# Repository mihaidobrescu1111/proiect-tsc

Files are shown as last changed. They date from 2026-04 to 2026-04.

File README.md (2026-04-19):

# InkTime - Hardware Design Repository

Proiect hardware pentru un smartwatch open-source, low-cost, realizat în Fusion 360 Electronics (EAGLE format `.sch` + `.brd`).

## Structura repository-ului

- Hardware
	- [Schematic.sch](Hardware/Schematic.sch)
	- [PCB.brd](Hardware/PCB.brd)
- Manufacturing
	- (de adăugat la EVT: `gerbers.zip`, `.bom`, `.cpl`)
- Mechanical
	- (de adăugat la EVT: model complet `.step` și fișier Fusion360)
- Images
	- (de adăugat: randări PCB și ansamblu)

## Diagramă bloc

```mermaid
flowchart LR
  BATT["LiPo Battery"] --> PMIC["BQ25180 Charger + Power Path"]
  USB["USB-C J4"] --> ESD["USBLC6 ESD"]
  USB --> PMIC
  PMIC --> SYS["System Rail"]

  SYS --> MCU["nRF52840 U1"]
  SYS --> FG["MAX17048 Fuel Gauge U3"]
  SYS --> HAPTIC["DRV2605 Vibrator Driver IC1"]
  SYS --> EPDPWR["RT6160 plus passives IC9"]

  MCU --> RFM["Matching L/C"]
  RFM --> ANT["2450AT18B100E Antenna"]

  MCU --> SWD["TC2030 SWD Header + Test Pads"]
  MCU --> DISP["EPD Connector J1"]
  MCU --> BTN["3 Buttons"]
```

## BOM (Bill of Materials)

| Ref / Grup | Componentă | Qty | Funcție | JLC / Source link | Datasheet |
|---|---|---:|---|---|---|
| `U1` | nRF52840-QFAA | 1 | MCU BLE + USB | https://jlcpcb.com/parts?searchTxt=nRF52840 | https://infocenter.nordicsemi.com/pdf/nRF52840_PS_v1.1.pdf |
| `IC1` | DRV2605 | 1 | Driver haptic | https://jlcpcb.com/parts?searchTxt=DRV2605 | https://www.ti.com/lit/ds/symlink/drv2605.pdf |
| `IC9` | RT6160A | 1 | Convertor DC/DC pentru rail-uri EPD | https://jlcpcb.com/parts?searchTxt=RT6160 | https://www.richtek.com/assets/product_file/RT6160A/DS6160A-05.pdf |
| `U3` | MAX17048G+T10 | 1 | Fuel gauge Li-Ion | https://jlcpcb.com/parts?searchTxt=MAX17048 | https://www.analog.com/media/en/technical-documentation/data-sheets/MAX17048-MAX17049.pdf |
| `ANT1` | 2450AT18B100E | 1 | Antenă 2.4 GHz | https://jlcpcb.com/parts?searchTxt=2450AT18B100E | https://www.johansontechnology.com/datasheets/2450AT18B100E.pdf |
| `J4` | USB-C 16P (KH-TYPE-C-16P) | 1 | Alimentare + USB | https://jlcpcb.com/parts?searchTxt=TYPE-C-16P | https://datasheet.lcsc.com/lcsc/2006231106_Kinghelm-KH-TYPE-C-16P_C709357.pdf |
| `D1` | USBLC6-2SC6Y | 1 | Protecție ESD USB | https://jlcpcb.com/parts?searchTxt=USBLC6-2SC6Y | https://www.st.com/resource/en/datasheet/usblc6-2.pdf |
| `D3`,`D4`,`D5` | MBR0530 | 3 | Schottky diode | https://jlcpcb.com/parts?searchTxt=MBR0530 | https://www.onsemi.com/pdf/datasheet/mbr0530t1-d.pdf |
| `Q3` | SI1308EDL | 1 | MOSFET control alimentare | https://jlcpcb.com/parts?searchTxt=SI1308EDL | https://www.vishay.com/docs/63399/si1308edl.pdf |
| `DMG2305UX-7` | PMOS | 1 | Comutare rail | https://jlcpcb.com/parts?searchTxt=DMG2305UX | https://www.diodes.com/assets/Datasheets/DMG2305UX.pdf |
| `J1` | 503480-2400 | 1 | Conector display / FPC | https://jlcpcb.com/parts?searchTxt=503480-2400 | https://www.molex.com/pdm_docs/sd/5034802400_sd.pdf |
| `J2` | TC2030-IDC | 1 | Debug/programare SWD | https://www.tag-connect.com/product/tc2030-idc-nl | https://www.tag-connect.com/wp-content/uploads/bsk-pdf-manager/TC2030-IDC-NL.pdf |
| `SW_UP`,`SW_ENT`,`SW_DN` | EVPAKE31A | 3 | Butoane UI | https://jlcpcb.com/parts?searchTxt=EVP-AKE31A | https://industrial.panasonic.com/cdbs/www-data/pdf/ASQ0000/ASQ0000CE153.pdf |
| `X1` | 32 MHz crystal | 1 | Clock HF MCU | https://jlcpcb.com/parts?searchTxt=32MHz%202016 | https://www.nxp.com/docs/en/data-sheet/NX3225SA.pdf |
| `X2` | 32.768 kHz crystal | 1 | RTC clock | https://jlcpcb.com/parts?searchTxt=32.768kHz%203215 | https://www.abracon.com/datasheets/ABS06.pdf |
| `R*` | Rezistențe 0201 | 15 | Bias, pull-up/pull-down, sense | https://jlcpcb.com/parts?searchTxt=0201%20resistor | - |
| `C*`,`EPD_C*` | Condensatoare 0201/0402/0603 | 39 | Decuplare, filtrare, RF matching, EPD charge pump | https://jlcpcb.com/parts?searchTxt=0201%20capacitor | - |
| `L1`,`L2`,`L3`,`L5`,`L7` | Inductoare (RF + power) | 5 | Matching RF + convertoare | https://jlcpcb.com/parts?searchTxt=0402%20inductor | - |
| `TP_*` | Test pads TP20R | 14 | DFT: SWD, alimentări, I2C, reset | https://jlcpcb.com/parts?searchTxt=test%20point | - |

## Funcționalitate hardware detaliată

### Domeniu alimentare

- Intrare alimentare prin USB-C (`J4`) + baterie LiPo.
- Lanț PMIC/charger (`BQ25180`) definit în schemă.
- Fuel gauge (`MAX17048`, `U3`) pentru estimarea stării bateriei.
- Convertor boost/buck (`RT6160`, `IC9`) pentru rail-uri auxiliare folosite de subsistemul display/EPD.
- Diode Schottky (`D3..D5`) și MOSFET-uri (`Q3`, `DMG2305UX-7`) pentru protecție/comutare rail.

### Sub-sistem MCU + RF

- MCU principal: `nRF52840` (`U1`).
- Clock-uri externe:
	- `X1` 32 MHz pentru radio/HF.
	- `X2` 32.768 kHz pentru RTC/low-power.
- Lanț RF de matching cu `L1`, `L3`, `C3`, `C4` către `ANT1`.

### Interfețe externe și debug

- USB-C + protecție ESD (`D1`).
- Header SWD Tag-Connect (`J2`) + test pads (`TP_SWDIO`, `TP_SWDCLK`, `TP_SWO`, `TP_RESET`).
- Test pads de alimentare și I2C (`TP_3V3`, `TP_VBAT`, `TP_GND`, `TP_SDA`, `TP_SCL`, etc.).

### Sub-sistem UI / haptic / display

- 3 butoane (`SW_UP`, `SW_ENT`, `SW_DN`).
- Driver haptic `DRV2605` (`IC1`).
- Conector display (`J1`) + pasive dedicate EPD (`EPD_C*`, `R_PWR_EPD`, etc.).

## Mapare pini nRF52840

| Pin nRF52840 | Net | Rol |
|---|---|---|
| `D+` | `N$58` | USB data plus (neconfirmat funcțional în documentația text-only) |
| `D-` | `N$59` | USB data minus (neconfirmat funcțional în documentația text-only) |
| `SWDCLK` | `SWDCLK` | Debug clock expus la TP_SWDCLK și header SWD |
| `SWDIO` | `SWDIO` | Debug data bidirecțional expus la TP_SWDIO și header SWD |
| `SWO` | `SWO` | Serial Wire Output (trace/debug) expus la TP_SWO |
| `NRST` | `NRST` | Reset hardware expus la TP_RESET |
| `I2C_SCL` | `I2C_SCL` | Magistrală I2C clock expusă la TP_SCL |
| `I2C_SDA` | `I2C_SDA` | Magistrală I2C data expusă la TP_SDA |
| `VDD` monitor/test | `VDD_3V3`, `VDD_3V3_MON` | Rail principal 3V3 + testpoint monitor dedicat |
| `VREG` | `VREG` | Rail regulator intern/auxiliar expus la TP_VREG |
| `VBAT` | `VBAT` | Rail baterie expus la TP_VBAT |
| `ANT` | `RF_MCU_MATCH` -> `RF_MATCH_ANT` | Lanț RF: pin ANT MCU -> matching -> antenă |
| `EPD control` | `EPD_OP`, `EPD_ON` | Semnale EPD expuse în DFT prin TP_OP/TP_ON |
| `XC1`, `XC2` | `N$78`, `N$79` | Cristal 32 MHz (neconfirmat pentru redenumire în etapa text-only) |
| `P0.00/XL1`, `P0.01/XL2` | `N$112`, `N$114` | Cristal 32.768 kHz (neconfirmat pentru redenumire în etapa text-only) |
| `VBUS`, `VDDH`, `DECx`, `VSS` | diverse `N$xx` și `GND` | Alimentare/decuplare conform recomandări Nordic (parțial neconfirmat) |

### GPIO generale

`P0.02 ... P0.31`, `P1.00 ... P1.15` sunt prezente pe neturi interne `N$44...N$111`.

## Consumul de putere (power budget estimativ, fără măsurători)

Estimările de mai jos sunt orientative și bazate pe:

- valori tipice din datasheet-uri (`nRF52840`, `MAX17048`, `DRV2605`, `RT6160A`, plus curenți pasivi/leakage)
- arhitectura din schemă (rail-uri separate pentru MCU, EPD power path și haptic)
- ipoteză de alimentare LiPo în domeniul nominal, fără derating termic sever

Nu reprezintă rezultate de test în laborator.

### Scenarii de consum

| Scenariu | Interval estimat | Bază estimare |
|---|---:|---|
| Sleep | `15 ... 60 µA` | nRF52840 în low-power + fuel gauge activ + leakage rail-uri |
| Activ BLE periodic | `1.5 ... 6 mA` mediu | duty-cycle radio BLE + CPU wakeups periodice + periferice de bază |
| Refresh display | `8 ... 25 mA` pe durata refresh | convertor EPD (`RT6160A`) + comutări pe rail-urile EPD + control MCU |
| Haptic activ | `20 ... 85 mA` în impuls | `DRV2605` + motor/vibrator (depinde puternic de pattern/amplitudine) |

Energia pentru o baterie de capacitate $C_{bat}$ [mAh] la curent mediu $I_{avg}$ [mA]:

$$
t_{autonomie}[h] \approx \frac{C_{bat}}{I_{avg}}
$$

Exemple numerice (cu ipoteze explicite):

- Caz A, baterie `180 mAh`, profil mixt cu $I_{avg} = 2.5$ mA (BLE periodic + refresh EPD ocazional):

$$
t \approx \frac{180}{2.5} = 72\ h \approx 3.0\ zile
$$

- Caz B, baterie `300 mAh`, profil predominant sleep cu burst-uri, $I_{avg} = 0.8$ mA:

$$
t \approx \frac{300}{0.8} = 375\ h \approx 15.6\ zile
$$

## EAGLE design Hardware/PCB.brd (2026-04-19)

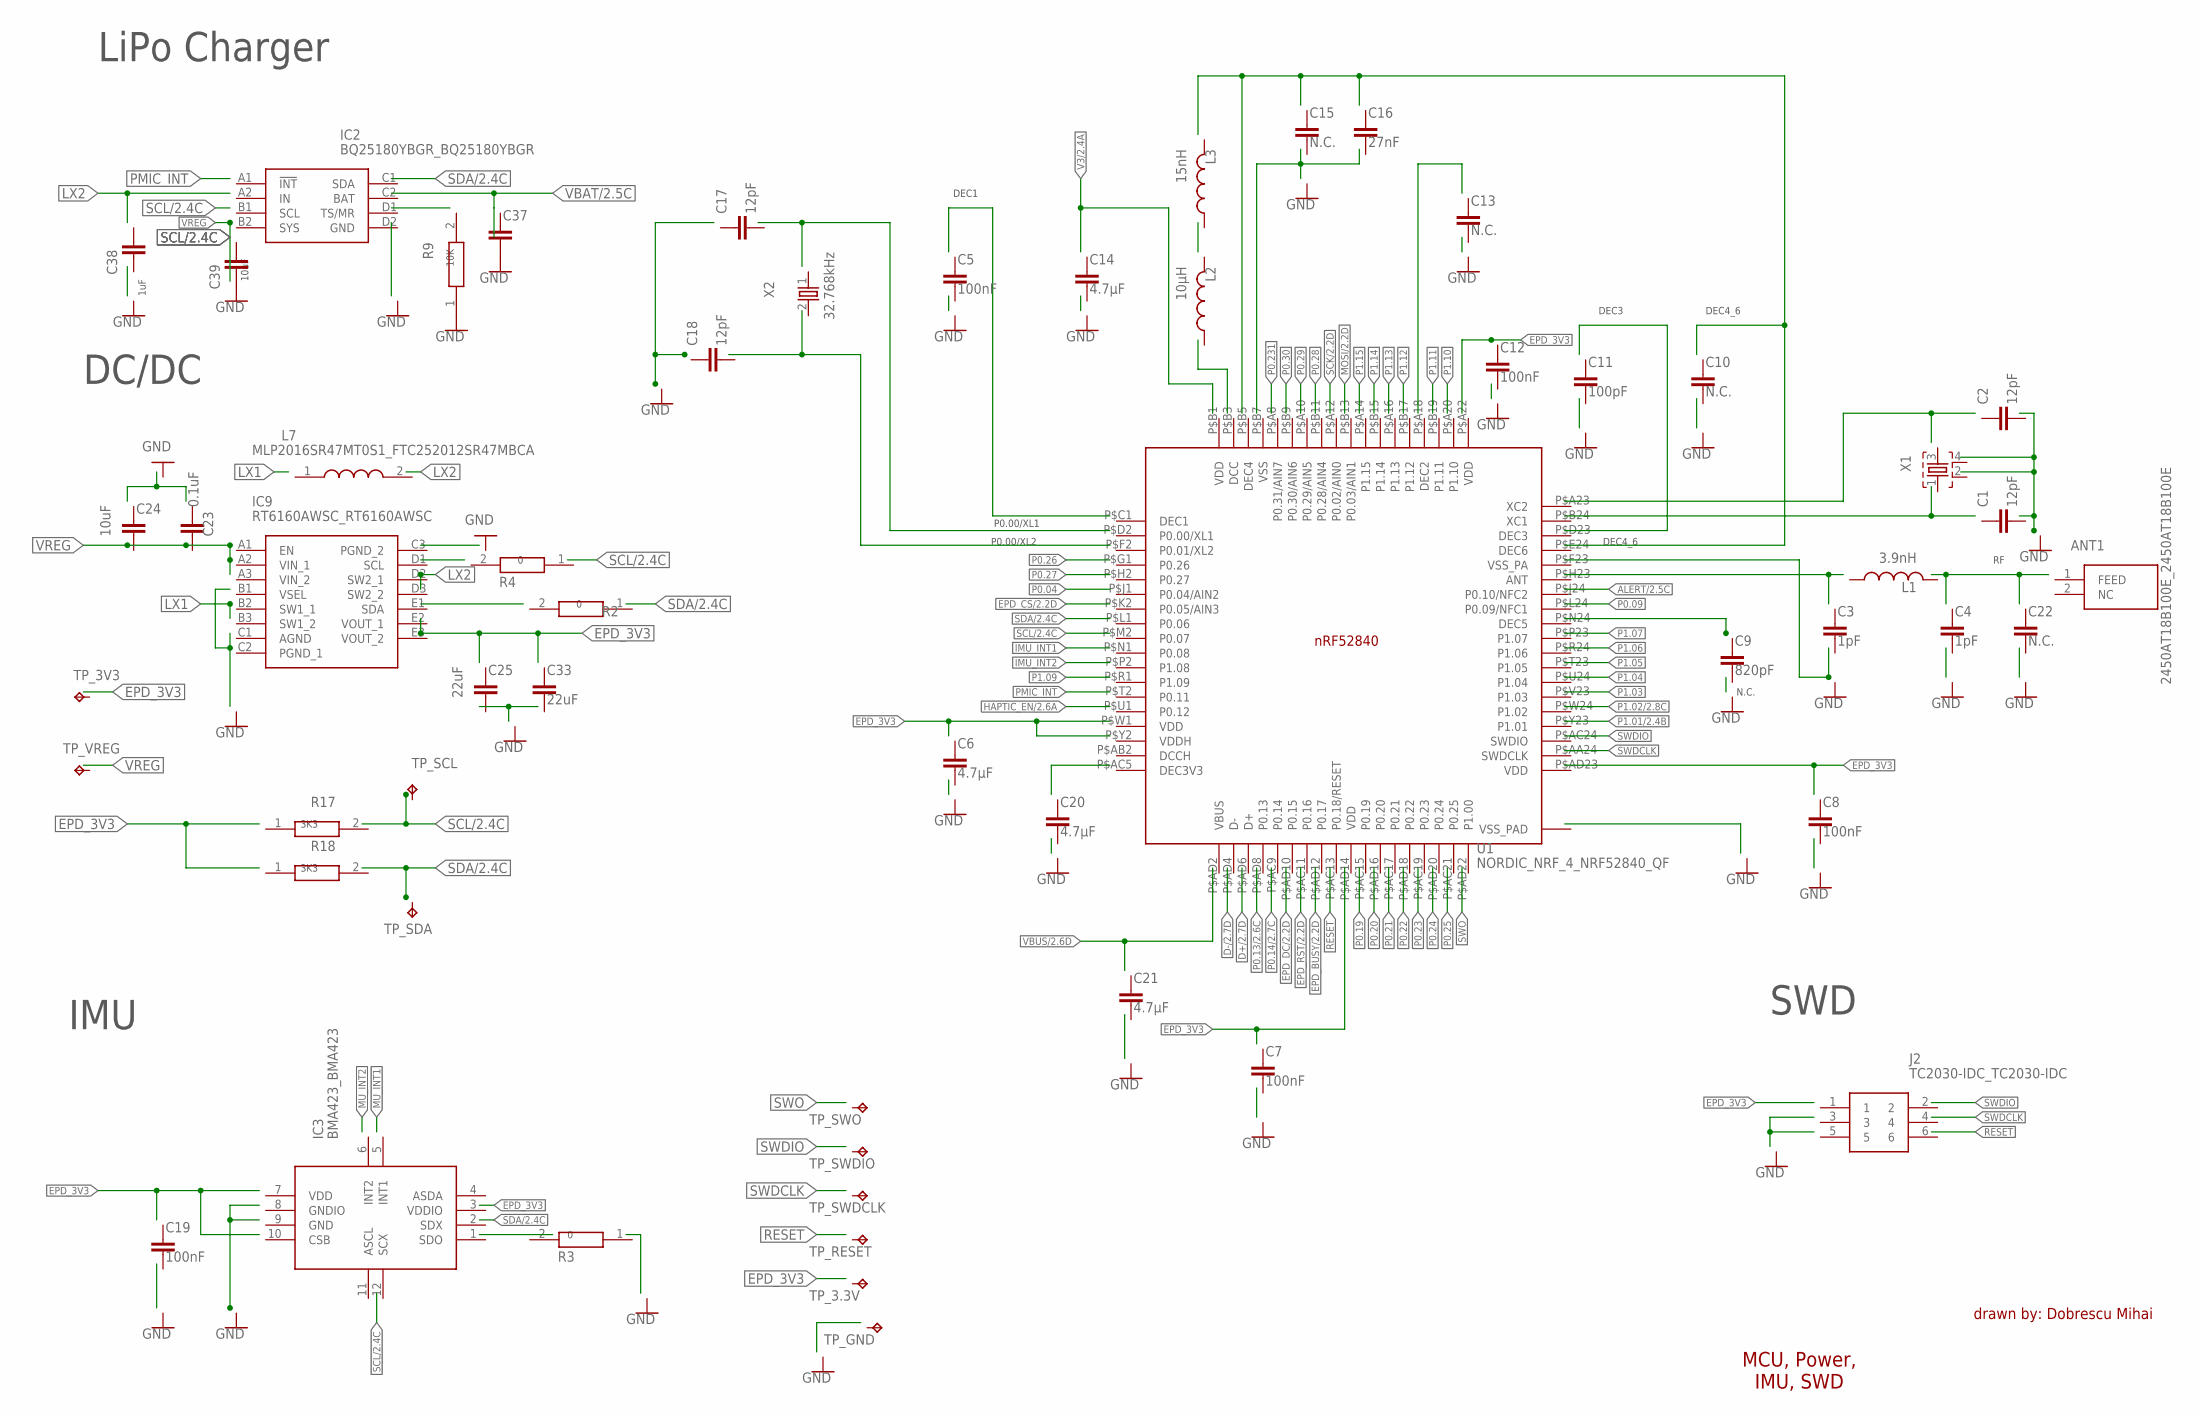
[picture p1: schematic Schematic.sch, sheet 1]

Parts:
ANT1: 2450AT18B100E_2450AT18B100E; 2450AT18B100E_ANTC3216X140N
C1, C2, C17, C18: 12pF; NORDIC_NRF_3_RESC0201_L
C3, C4: 1pF; NORDIC_NRF_3_RESC0201_L
C5, C7, C8, C12, C19: 100nF; NORDIC_NRF_3_RESC0201_L
C6, C14, C20, C21: 4.7µF; NORDIC_NRF_3_RESC0201_L
C9: 820pF; NORDIC_NRF_3_RESC0201_L
C10, C13, C15, C22: N.C.; NORDIC_NRF_3_RESC0201_L
C11: 100pF; NORDIC_NRF_3_RESC0201_L
C16: 27nF; NORDIC_NRF_3_RESC0201_L
C23: 0.1uF; NORDIC_NRF_3_RESC0201_L
C24: 10uF; NORDIC_NRF_3_RESC0201_L
C25, C33: 22uF; NORDIC_NRF_3_RESC0201_L
C37, C38, C39: NORDIC_NRF_3_CAPACITOR_0201_L; NORDIC_NRF_3_RESC0201_L
IC2: BQ25180YBGR_BQ25180YBGR; BQ25180YBGR_BGA8C40P2X4_100X155X50
IC3: BMA423_BMA423
IC9: RT6160AWSC_RT6160AWSC; RT6160AWSC_BGA15C40P3X5_140X230X60
J2: TC2030-IDC_TC2030-IDC; TC2030-IDC_TC2030IDC
L1: 3.9nH; NORDIC_NRF_2_RESC0402_L
L2: 10µH; NORDIC_NRF_2_RESC0402_L
L3: 15nH; NORDIC_NRF_2_RESC0402_L
L7: MLP2016SR47MT0S1_FTC252012SR47MBCA; MLP2016SR47MT0S1_INDC2016X100N
R2, R3, R4, R9, R17, R18: ERA-1AEB3401C_CPF0201D7K68C1; ERA-1AEB3401C_0201
TP_3.3V, TP_3V3: HECTOR_WATCH_1_TPTP20R; HECTOR_WATCH_1_TP20R
TP_GND: HECTOR_WATCH_1_TPTP20R; HECTOR_WATCH_1_TP20R
TP_RESET: HECTOR_WATCH_1_TPTP20R; HECTOR_WATCH_1_TP20R
TP_SCL: HECTOR_WATCH_1_TPTP20R; HECTOR_WATCH_1_TP20R
TP_SDA: HECTOR_WATCH_1_TPTP20R; HECTOR_WATCH_1_TP20R
TP_SWDCLK: HECTOR_WATCH_1_TPTP20R; HECTOR_WATCH_1_TP20R
TP_SWDIO: HECTOR_WATCH_1_TPTP20R; HECTOR_WATCH_1_TP20R
TP_SWO: HECTOR_WATCH_1_TPTP20R; HECTOR_WATCH_1_TP20R
TP_VREG: HECTOR_WATCH_1_TPTP20R; HECTOR_WATCH_1_TP20R
U1: NORDIC_NRF_4_NRF52840_QF; NORDIC_NRF_4_AQFN50P700X700X85_HS-74N
X1: NORDIC_NRF_XTAL_32MHZ; NORDIC_NRF_BT-XTAL_2016_N
X2: 32.768kHz; NORDIC_NRF_1_XTAL_3215_N

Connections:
GND: C3.2, C4.2, C5.2, C6.2, C7.2, C8.2, C9.2, C10.2, C11.2, C12.2, C13.2, C14.2, C15.2, C16.2, C19.2, C20.2, C21.2, C22.2, C23.1, C24.1, C25.2, C33.2, C37.2, C38.2, C39.1, C39.2, IC2.B2 (SYS), IC2.D2 (GND), IC9.B1 (VSEL), IC9.C1 (AGND), IC9.C2 (PGND_1), IC9.C3 (PGND_2), J2.3, J2.5, R3.1, R9.1, TP_GND.TP, U1.P$74 (VSS_PAD), U1.P$75 (VSS_PAD), U1.P$76 (VSS_PAD), U1.P$77 (VSS_PAD), U1.P$78 (VSS_PAD), U1.P$79 (VSS_PAD), U1.P$80 (VSS_PAD), U1.P$81 (VSS_PAD), U1.P$82 (VSS_PAD), U1.P$83 (VSS_PAD), U1.P$84 (VSS_PAD), U1.P$85 (VSS_PAD), U1.P$86 (VSS_PAD), U1.P$87 (VSS_PAD), U1.P$88 (VSS_PAD), U1.P$89 (VSS_PAD), U1.P$90 (VSS_PAD), U1.P$B7 (VSS), U1.P$F23 (VSS_PA); also elsewhere on the board
I2C_SCL: TP_SCL.TP
I2C_SDA: TP_SDA.TP
unnamed: IC2.D1 (TS/MR), R9.2
unnamed: C38.1, IC2.A2 (IN)
unnamed: C37.1, IC2.C2 (BAT)
unnamed: C23.2, C24.2, IC9.A1 (EN), IC9.A2 (VIN_1), IC9.A3 (VIN_2)
unnamed: IC9.B2 (SW1_1), IC9.B3 (SW1_2)
unnamed: IC9.D1 (SCL), R4.2
unnamed: R17.1, R18.1
unnamed: IC9.D2 (SW2_1), IC9.D3 (SW2_2)
unnamed: C25.1, C33.1, IC9.E2 (VOUT_1), IC9.E3 (VOUT_2)
unnamed: IC9.E1 (SDA), R2.2
unnamed: C19.1, IC3.7 (VDD), IC3.10 (CSB)
unnamed: IC3.8 (GNDIO), IC3.9 (GND)
unnamed: IC3.1 (SDO), R3.2
unnamed: C7.1, U1.P$AD14 (VDD)
unnamed: C21.1, U1.P$AD2 (VBUS)
unnamed: C8.1, U1.P$AD23 (VDD)
unnamed: C10.1, C15.1, C16.1, L3.2, U1.P$B5 (DEC4), U1.P$E24 (DEC6)
unnamed: C11.1, U1.P$D23 (DEC3)
unnamed: C1.1, U1.P$B24 (XC1), X1.1
unnamed: C2.1, U1.P$A23 (XC2), X1.3
unnamed: C1.2, C2.2, X1.2, X1.4
unnamed: C12.1, U1.P$A22 (VDD)
unnamed: C13.1, U1.P$A18 (DEC2)
unnamed: L2.2, L3.1
unnamed: L2.1, U1.P$B3 (DCC)
unnamed: C20.1, U1.P$AC5 (DEC3V3)
unnamed: C6.1, U1.P$W1 (VDD), U1.P$Y2 (VDDH)
unnamed: C14.1, U1.P$B1 (VDD)
unnamed: C5.1, U1.P$C1 (DEC1)
unnamed: C17.2, U1.P$D2 (P0.00/XL1), X2.1
unnamed: C18.2, U1.P$F2 (P0.01/XL2), X2.2
NRST: TP_RESET.TP
RF_MATCH_ANT: ANT1.1 (FEED), C4.1, C22.1, L1.2
RF_MCU_MATCH: C3.1, L1.1, U1.P$H23 (ANT)
SDA/2.4C: IC2.C1 (SDA)
SWDCLK: TP_SWDCLK.TP
SWDIO: TP_SWDIO.TP
SWO: TP_SWO.TP
VDD_3V3: TP_3V3.TP
VDD_3V3_MON: TP_3.3V.TP
VREG: TP_VREG.TP

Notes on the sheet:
LiPo Charger
10K
DC/DC
3K3
10uF
1uF
IMU
N.C.
DEC3
DEC4_6
DEC1
P0.00/XL1
P0.00/XL2
drawn by: Dobrescu Mihai
MCU, Power, IMU, SWD
SWD

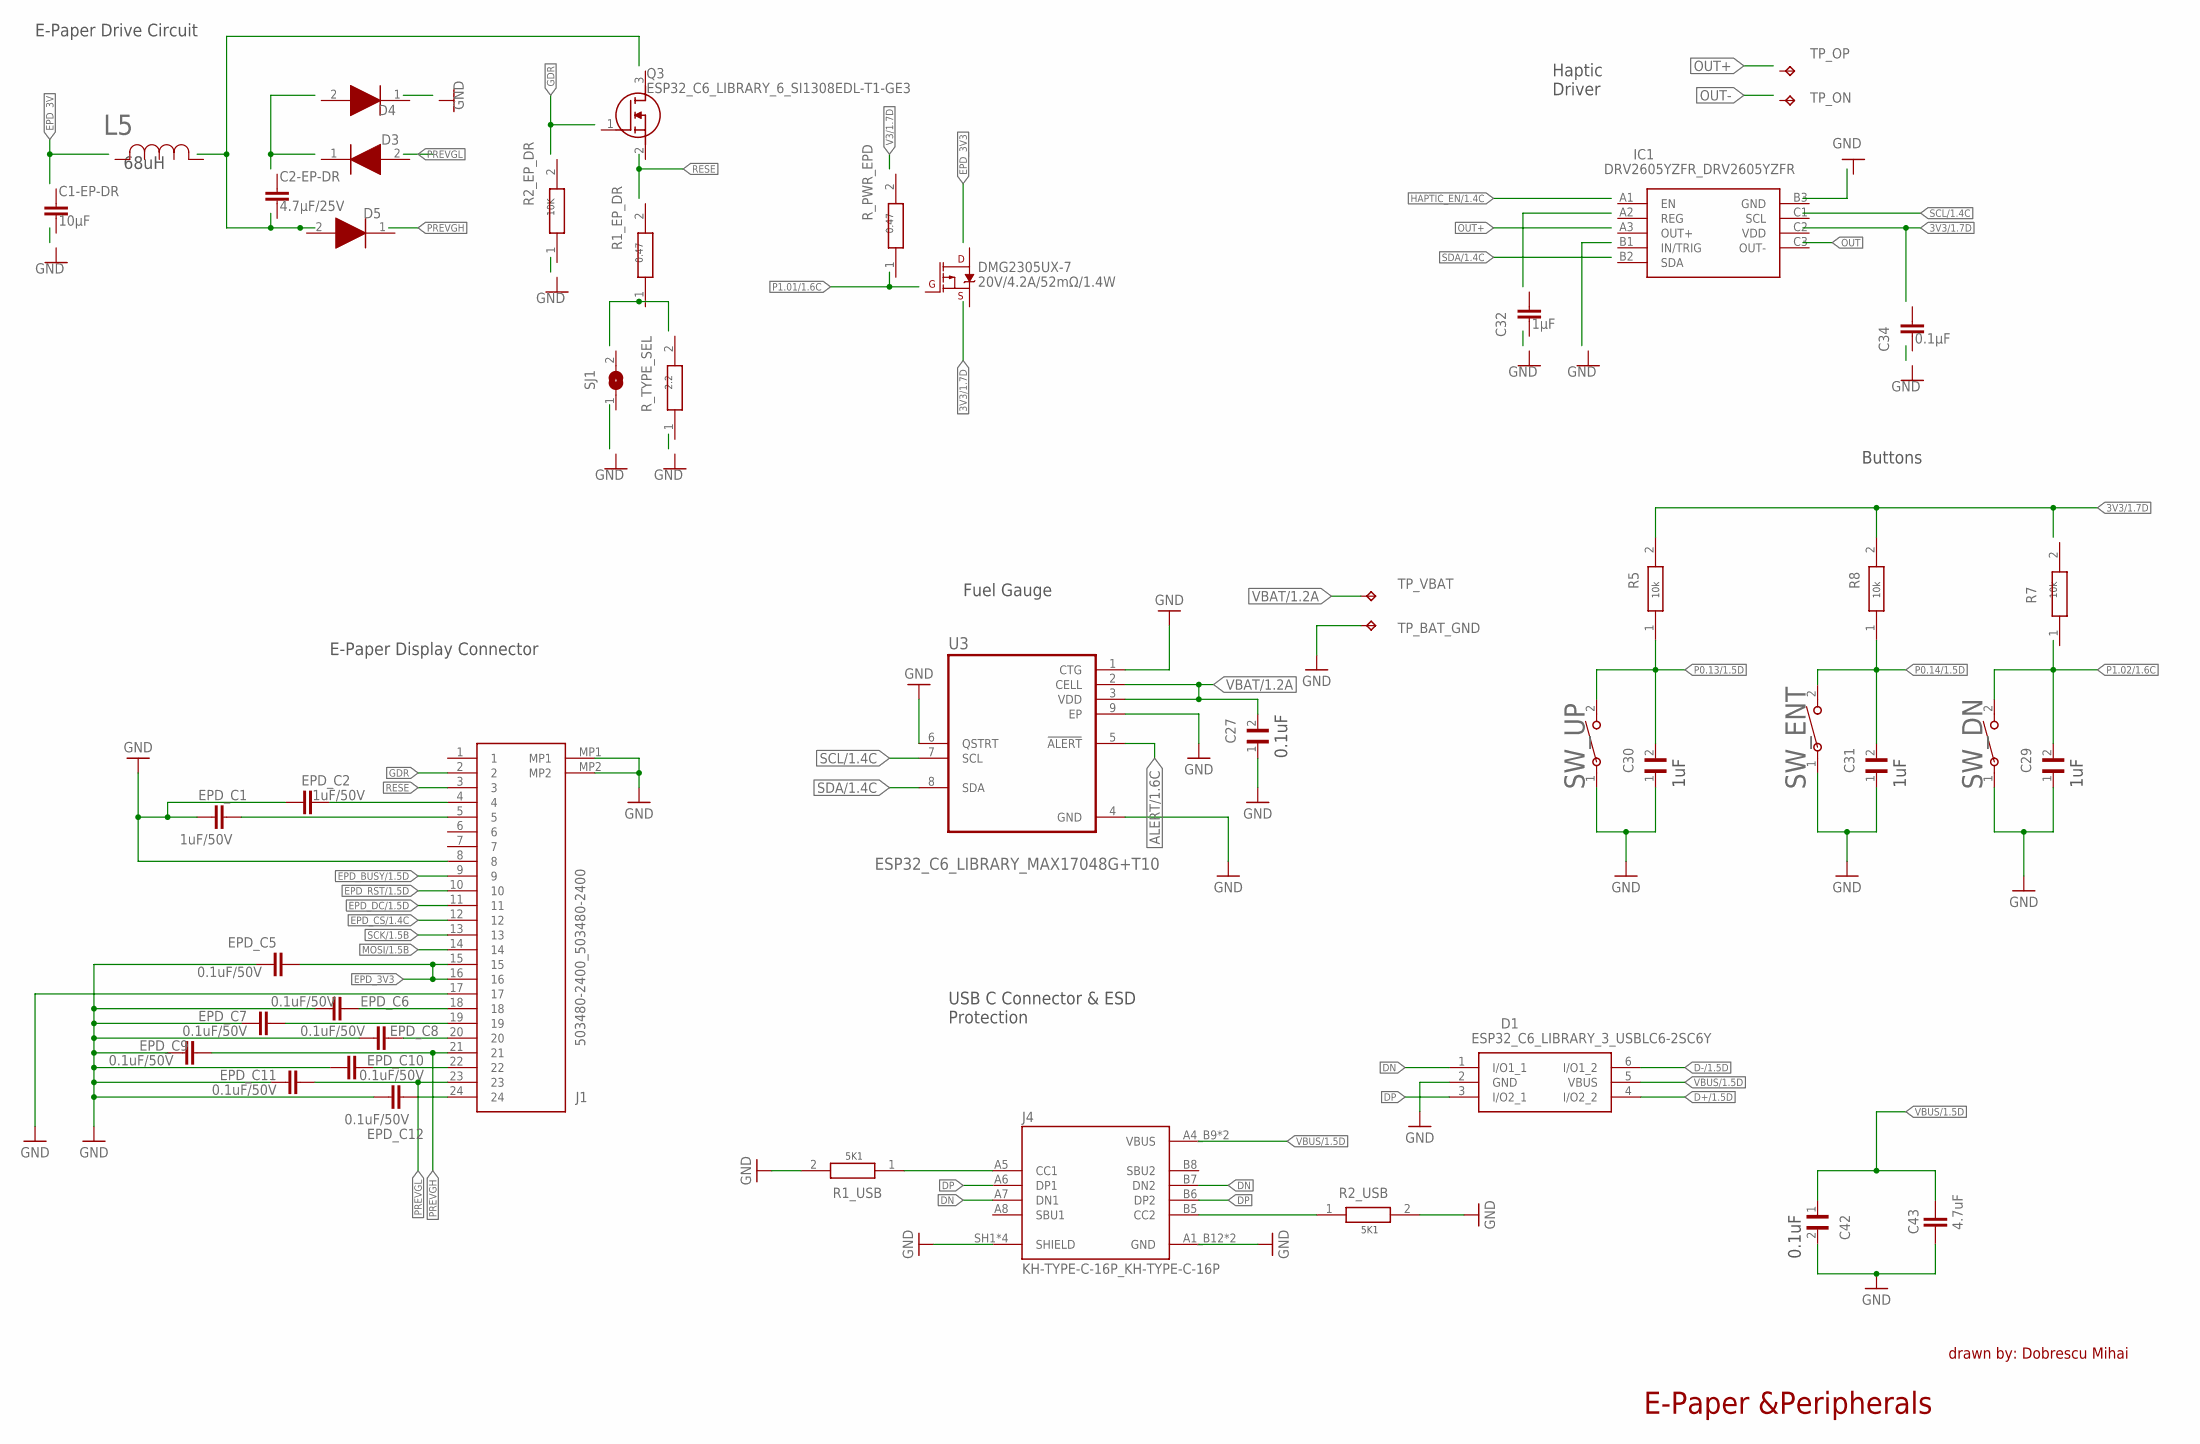
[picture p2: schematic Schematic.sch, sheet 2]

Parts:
C1-EP-DR: 10µF; NORDIC_NRF_3_RESC0201_L
C2-EP-DR: 4.7µF/25V; NORDIC_NRF_3_RESC0201_L
C27, C29, C30, C31, C42: GRM011R60J152KE01L_2_GRM011R60J152KE01L; GRM011R60J152KE01L_2_CAPC0201X13N
C32: 1µF; NORDIC_NRF_3_RESC0201_L
C34: 0.1µF; NORDIC_NRF_3_RESC0201_L
C43: 4.7uF; NORDIC_NRF_3_RESC0201_L
D1: ESP32_C6_LIBRARY_3_USBLC6-2SC6Y; ESP32_C6_LIBRARY_3_SOT95P280X145-6N
D3, D4, D5: ESP32_C6_LIBRARY_5_MBR0530; ESP32_C6_LIBRARY_5_SOD3716X135N
DMG2305UX-7: 20V/4.2A/52mΩ/1.4W; ESP32_C6_LIBRARY_4_ESP32_C6_LIBRARY_4_ESP32_C6_LIBRARY_4_ES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
EPD_C1, EPD_C2: 1uF/50V; NORDIC_NRF_3_RESC0201_L
EPD_C5, EPD_C6, EPD_C7, EPD_C8, EPD_C9, EPD_C10, EPD_C11, EPD_C12: 0.1uF/50V; NORDIC_NRF_3_RESC0201_L
IC1: DRV2605YZFR_DRV2605YZFR; DRV2605YZFR_BGA9C50P3X3_144X144X62
J1: 503480-2400_503480-2400; 503480-2400_5034802400
J4: KH-TYPE-C-16P_KH-TYPE-C-16P; KH-TYPE-C-16P_KINGHELM_KH-TYPE-C-16P
L5: 68uH; ESP32_C6_LIBRARY_2_IND_4828-WE-TPC_WRE
Q3: ESP32_C6_LIBRARY_6_SI1308EDL-T1-GE3; ESP32_C6_LIBRARY_6_SOT65P210X110-3N
R1_EP_DR, R1_USB, R2_EP_DR, R2_USB, R5, R7, R8: ERA-1AEB3401C_CPF0201D7K68C1; ERA-1AEB3401C_0201
R_PWR_EPD: ERA-1AEB3401C_CPF0201D7K68C1; ERA-1AEB3401C_0201
R_TYPE_SEL: ERA-1AEB3401C_CPF0201D7K68C1; ERA-1AEB3401C_0201
SJ1: ESP32_C6_LIBRARY_7_JUMPER_SJ
SW_DN: 2025-10-22_07-23-44_LIBRARY_EVP-AKE31ASW_EVP-AKE3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; 2025-10-22_07-23-44_LIBRARY_SW_EVP-AKE31A_PAN
SW_ENT: 2025-10-22_07-23-44_LIBRARY_EVP-AKE31ASW_EVP-AKE3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; 2025-10-22_07-23-44_LIBRARY_SW_EVP-AKE31A_PAN
SW_UP: 2025-10-22_07-23-44_LIBRARY_EVP-AKE31ASW_EVP-AKE3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; 2025-10-22_07-23-44_LIBRARY_SW_EVP-AKE31A_PAN
TP_BAT_GND: HECTOR_WATCH_1_TPTP20R; HECTOR_WATCH_1_TP20R
TP_ON: HECTOR_WATCH_1_TPTP20R; HECTOR_WATCH_1_TP20R
TP_OP: HECTOR_WATCH_1_TPTP20R; HECTOR_WATCH_1_TP20R
TP_VBAT: HECTOR_WATCH_1_TPTP20R; HECTOR_WATCH_1_TP20R
U3: ESP32_C6_LIBRARY_MAX17048G+T10; ESP32_C6_LIBRARY_SON50P200X200X80-9N

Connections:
EPD_ON: TP_ON.TP
EPD_OP: TP_OP.TP
GND: C1-EP-DR.2, C27.1, C29.1, C30.1, C31.1, C32.2, C34.2, D1.2 (GND), D4.1 (K), EPD_C1.1, EPD_C2.1, EPD_C5.1, EPD_C6.1, EPD_C7.1, EPD_C8.1, EPD_C9.1, EPD_C10.1, EPD_C11.1, EPD_C12.1, IC1.B1 (IN/TRIG), IC1.B3 (GND), J1.8, J1.17, J1.MP1, J1.MP2, J4.A1_B12 (GND), J4.A12_B1 (GND), J4.SH1 (SHIELD), J4.SH2 (SHIELD), J4.SH3 (SHIELD), J4.SH4 (SHIELD), R1_USB.2, R2_EP_DR.1, R2_USB.2, R_TYPE_SEL.1, SJ1.1, SW_DN.1, SW_ENT.1, SW_UP.1, TP_BAT_GND.TP, U3.1 (CTG), U3.4 (GND), U3.6 (QSTRT), U3.9 (EP); also elsewhere on the board
GND1: R1_EP_DR.1, R_TYPE_SEL.2, SJ1.2
GND2: C29.2, R7.1, SW_DN.2
GND3: C31.2, R8.1, SW_ENT.2
GND4: C30.2, R5.1, SW_UP.2
unnamed: C1-EP-DR.1, L5.2
unnamed: C2-EP-DR.2, D5.2 (A), L5.1, Q3.3 (D)
unnamed: C2-EP-DR.1, D3.1 (K), D4.2 (A)
unnamed: Q3.1 (G), R2_EP_DR.2
unnamed: Q3.2 (S), R1_EP_DR.2
unnamed: DMG2305UX-7.1 (G), R_PWR_EPD.1
unnamed: C32.1, IC1.A2 (REG)
unnamed: C34.1, IC1.C2 (VDD)
unnamed: R5.2, R7.2, R8.2
unnamed: C27.2, U3.2 (CELL), U3.3 (VDD)
unnamed: EPD_C12.2, J1.24
unnamed: EPD_C2.2, J1.4
unnamed: EPD_C1.2, J1.5
unnamed: EPD_C5.2, J1.15, J1.16
unnamed: EPD_C11.2, J1.23
unnamed: EPD_C10.2, J1.22
unnamed: EPD_C9.2, J1.21
unnamed: EPD_C8.2, J1.20
unnamed: EPD_C7.2, J1.19
unnamed: EPD_C6.2, J1.18
unnamed: J4.A4_B9 (VBUS), J4.A9_B4 (VBUS)
unnamed: J4.B5 (CC2), R2_USB.1
unnamed: J4.A5 (CC1), R1_USB.1
unnamed: C42.2, C43.1
unnamed: C42.1, C43.2
VBAT: TP_VBAT.TP

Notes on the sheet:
E-Paper Drive Circuit
10K
0.47
2.2
68uH
Haptic Driver
Buttons
10k
1uF
Fuel Gauge
0.1uF
E-Paper Display Connector
USB C Connector & ESD Protection
5K1
E-Paper &Peripherals
drawn by: Dobrescu Mihai

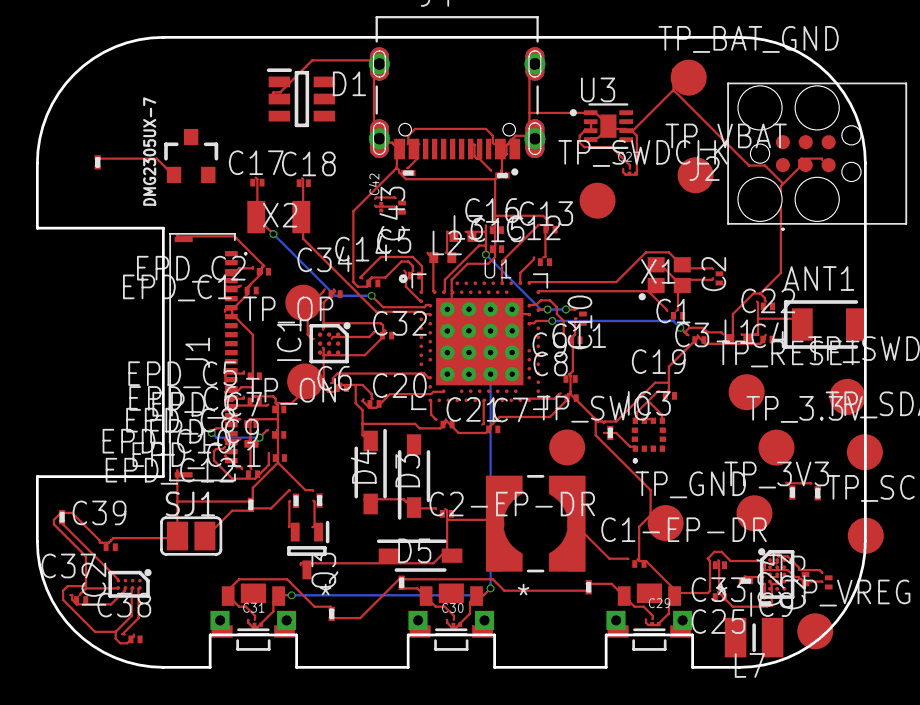
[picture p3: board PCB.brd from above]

Board: 2 copper layers, 46.0 x 35.0 mm, 105 parts (0 on the bottom side), 63 nets.

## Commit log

2026-04-10 Hardware files + readme and license
    [PCB.brd, Schematic.sch]
2026-04-19 Review (#8)
    * Revise nRF52840 pin mapping and power budget details
    Updated pin descriptions for nRF52840 and power consumption estimates.
    * Improve pcb in regards to review
    * Rename nets for clarity and consistency
    [PCB.brd, Schematic.sch]

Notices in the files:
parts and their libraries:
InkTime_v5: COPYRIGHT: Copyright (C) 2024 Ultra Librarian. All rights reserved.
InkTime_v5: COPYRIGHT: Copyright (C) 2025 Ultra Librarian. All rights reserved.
